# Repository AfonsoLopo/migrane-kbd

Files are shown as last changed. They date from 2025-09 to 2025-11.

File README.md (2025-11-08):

## MIGRANE
<p align="center">
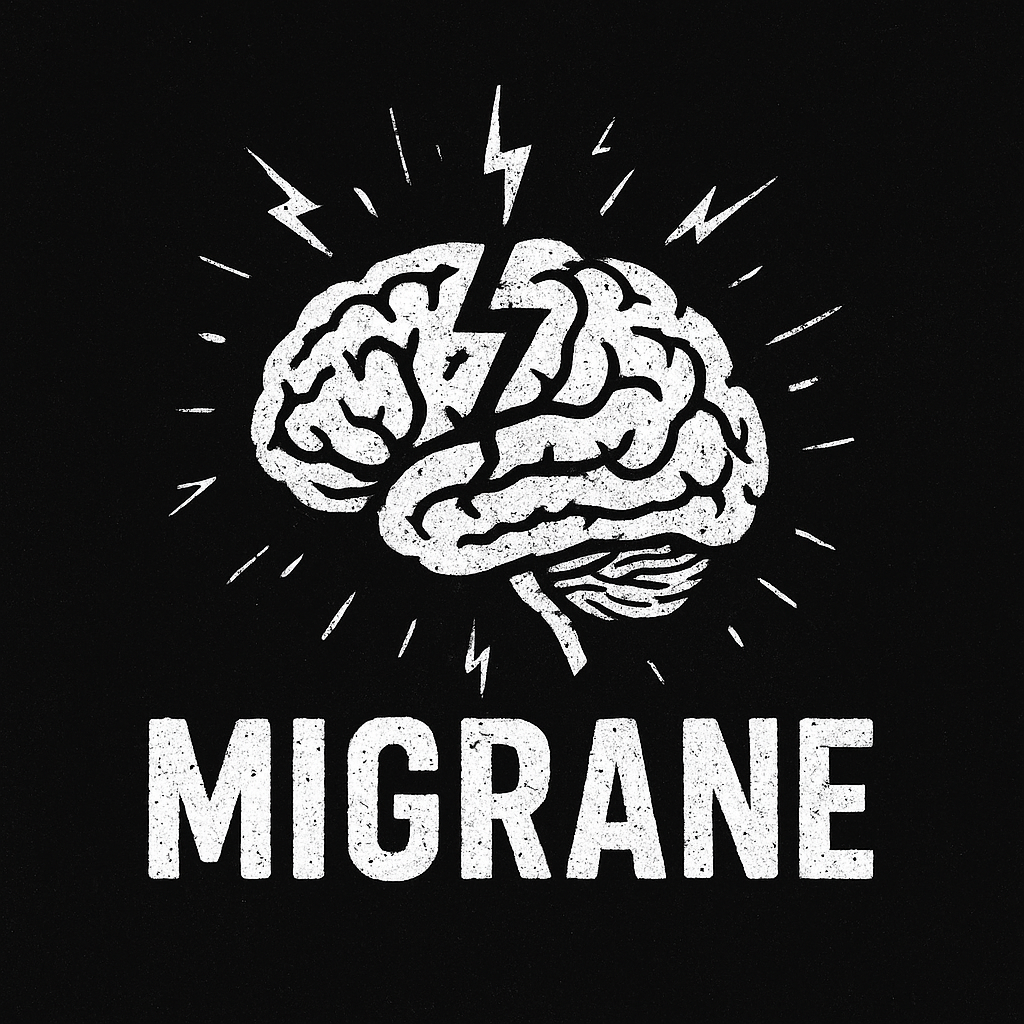
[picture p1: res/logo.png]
Migrane Keyboard logo

</p>

# Table of Contents: 
- [Specs](#Specs)
- [Assembly](#Assemby)
- [Firmware](#Firmware)

## Specs
<b>MCU</b> : STM32F446RCT6
<b>Number of Keys:</b> 64 Kailh choc hotswap sockets
<b>Number of LEDS:</b> 64 SK6812-mini e (1 per key) 
<b>Displays:</b> Adafruit 1.8" TFT Display
<b>Connection between halfs :</b> Serial over USB-C to USB-C cable
<b>Wire Debugger:</b> optional headers

## Assembly

    (TBD)

## Firmware

Board prepared to be used with qmk firmware.

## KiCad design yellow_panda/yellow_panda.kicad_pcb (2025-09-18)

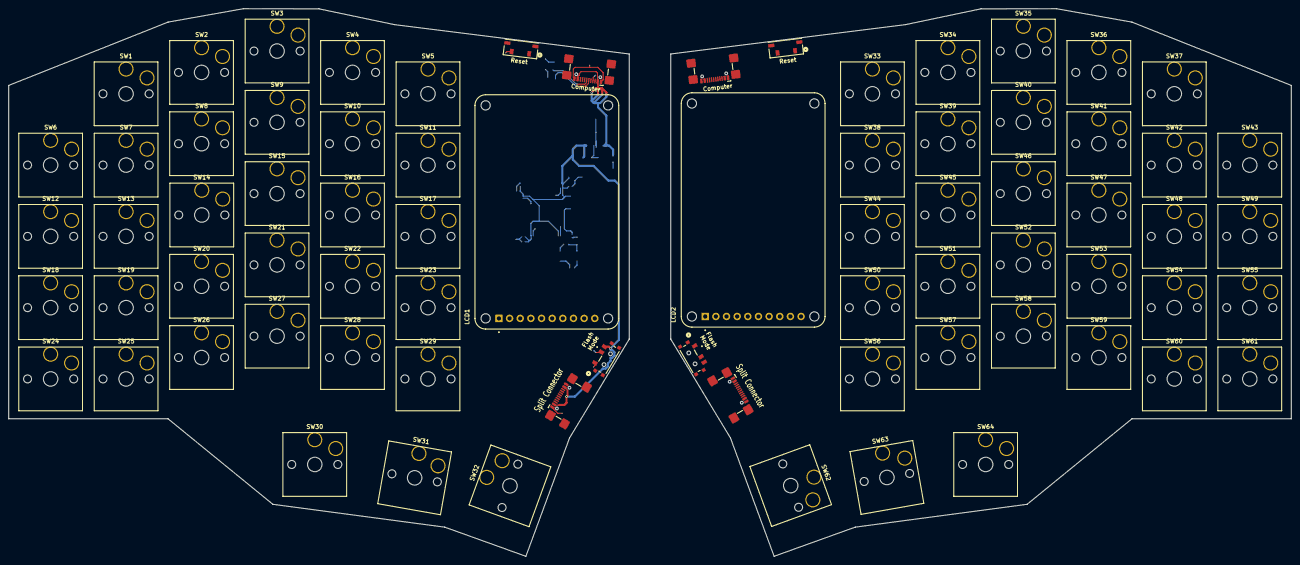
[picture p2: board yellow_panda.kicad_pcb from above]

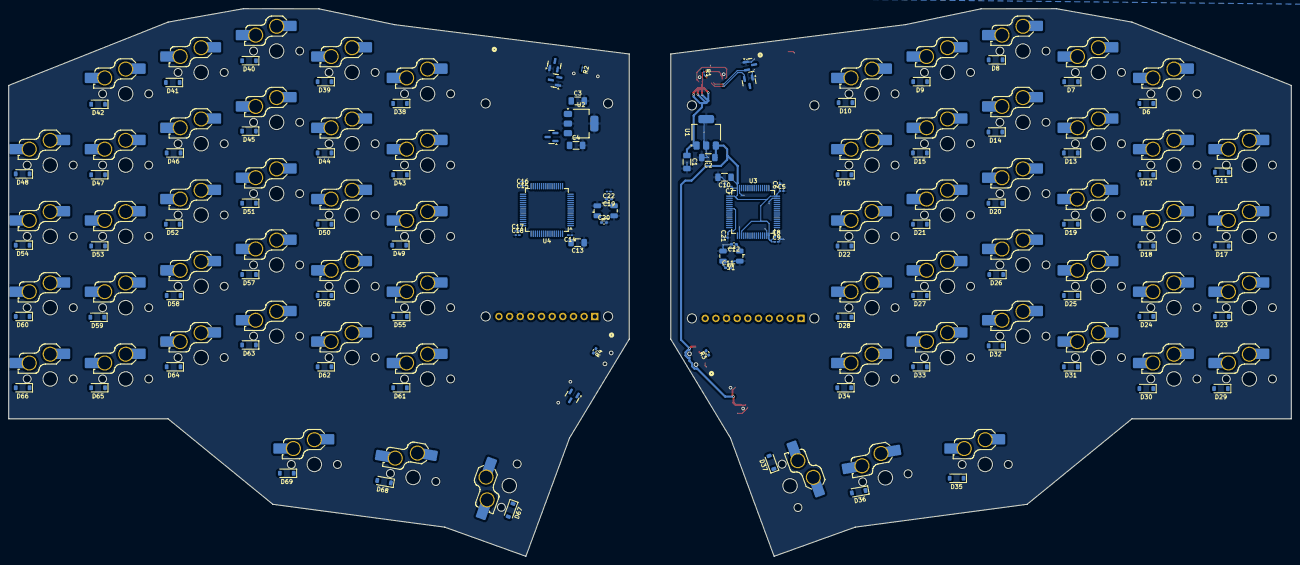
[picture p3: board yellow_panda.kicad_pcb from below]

Board: 2 copper layers, 305.9 x 130.6 mm, 176 parts (102 on the bottom side), 109 nets.

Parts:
C1, C2, C3, C4, C10, C13: 10uF; C_1206_3216Metric_Pad1.33x1.80mm_HandSolder
C5, C6, C7, C8, C9, C14, C15, C16, C17, C18, C21, C22: 100nF; C_0201_0603Metric_Pad0.64x0.40mm_HandSolder
C11, C12, C19, C20: 15pF; C_0402_1005Metric_Pad0.74x0.62mm_HandSolder
D1, D70: D_Schottky; D_SOT-23
D2, D3, D4, D5: 5V; D_SOT-23
D6, D7, D8, D9, D10, D11, D12, D13, D14, D15, D16, D17, D18, D19, D20, D21, D22, D23, D24, D25, D26, D27, D28, D29, D30, D31, D32, D33, D34, D35, D36, D37, D38, D39, D40, D41, D42, D43, D44, D45, D46, D47, D48, D49, D50, D51, D52, D53, D54, D55, D56, D57, D58, D59, D60, D61, D62, D63, D64, D65, D66, D67, D68, D69: D_SOD-123
LCD1, LCD2: I2C LCD; MODULE_358
P1, P2: USB_C_Plug_USB2.0; USB_C_Receptacle_GCT_USB4110
P3: Master Connection Plug; USB_C_Receptacle_GCT_USB4110
P4: Slave Connection Plug; USB_C_Receptacle_GCT_USB4110
R1, R2: 5.1kΩ; R_01005_0402Metric_Pad0.57x0.30mm_HandSolder
R3, R4: 10k; R_0402_1005Metric_Pad0.72x0.64mm_HandSolder
SW1, SW2, SW3, SW4, SW5, SW6, SW7, SW8, SW9, SW10, SW11, SW12, SW13, SW14, SW15, SW16, SW17, SW18, SW19, SW20, SW21, SW22, SW23, SW24, SW25, SW26, SW27, SW28, SW29, SW30, SW31, SW33, SW34, SW35, SW36, SW37, SW38, SW39, SW40, SW41, SW42, SW43, SW44, SW45, SW46, SW47, SW48, SW49, SW50, SW51, SW52, SW53, SW54, SW55, SW56, SW57, SW58, SW59, SW60, SW61, SW63, SW64: SW_Hotswap_Kailh_Choc_V1_Plated_1.00u
SW32, SW62: SW_Hotswap_Kailh_Choc_V1_Plated_1.50u
SW65, SW66: SW_SPDT; SLW-66527511-SMT-TR_CUD
SW67, SW68: SW_Push; SW_TL3330_EWI
U1, U2: LT1963AxST-3.3; SOT-223-3_TabPin2
U3, U4: STM32F446RCTx; LQFP-64_10x10mm_P0.5mm
Y1, Y2: 8MHz; Crystal_SMD_Abracon_ABM3B-4Pin_5.0x3.2mm

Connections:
+3.3V: C2.1, C5.1, C6.1, C7.1, C8.1, C9.1, C10.1, C13.2, C14.2, C15.2, C16.2, C17.2, C18.2, D1.1 (K), D70.1 (K), P3.A4 (VBUS), P3.A9 (VBUS), P3.B4 (VBUS), P3.B9 (VBUS), SW65.3 (C), U1.3 (OUT), U3.1 (VBAT), U3.19 (VDD), U3.32 (VDD), U3.48 (VDD), U3.64 (VDD), U4.1 (VBAT), U4.19 (VDD), U4.32 (VDD), U4.48 (VDD), U4.64 (VDD)
+5V: C1.1, C3.1, P1.A4 (VBUS), P1.A9 (VBUS), P1.B4 (VBUS), P1.B9 (VBUS), P2.A4 (VBUS), P2.A9 (VBUS), P2.B4 (VBUS), P2.B9 (VBUS), U1.1 (IN), U2.1 (IN)
/MasterSwitchMatrix/COL0a: SW6.1, SW12.1, SW18.1, SW24.1
/MasterSwitchMatrix/COL1a: SW1.1, SW7.1, SW13.1, SW19.1, SW25.1
/MasterSwitchMatrix/COL2a: SW2.1, SW8.1, SW14.1, SW20.1, SW26.1
/MasterSwitchMatrix/COL3a: SW3.1, SW9.1, SW15.1, SW21.1, SW27.1, SW30.1
/MasterSwitchMatrix/COL4a: SW4.1, SW10.1, SW16.1, SW22.1, SW28.1, SW31.1
/MasterSwitchMatrix/COL5a: SW5.1, SW11.1, SW17.1, SW23.1, SW29.1, SW32.1
/MasterSwitchMatrix/ROW0a: D6.1 (K), D7.1 (K), D8.1 (K), D9.1 (K), D10.1 (K)
/MasterSwitchMatrix/ROW1a: D11.1 (K), D12.1 (K), D13.1 (K), D14.1 (K), D15.1 (K), D16.1 (K)
/MasterSwitchMatrix/ROW2a: D17.1 (K), D18.1 (K), D19.1 (K), D20.1 (K), D21.1 (K), D22.1 (K)
/MasterSwitchMatrix/ROW3a: D23.1 (K), D24.1 (K), D25.1 (K), D26.1 (K), D27.1 (K), D28.1 (K)
/MasterSwitchMatrix/ROW4a: D29.1 (K), D30.1 (K), D31.1 (K), D32.1 (K), D33.1 (K), D34.1 (K)
/MasterSwitchMatrix/ROW6a: D35.1 (K), D36.1 (K), D37.1 (K)
/STM MCUs/BOOT0a: R3.1, U3.60 (BOOT0)
/STM MCUs/BOOT0b: R4.1, U4.60 (BOOT0)
/STM MCUs/OSC INa: C11.1, Y1.3
/STM MCUs/OSC INb: C19.1, Y2.3
/STM MCUs/OSC OUTa: C12.1, Y1.1
/STM MCUs/OSC OUTb: C20.1, Y2.1
/STM MCUs/RESETa: C21.2, SW67.1, U3.7 (NRST)
/STM MCUs/RESETb: C22.2, SW68.1, U4.7 (NRST)
/STM MCUs/SW_BOOT0a: R3.2, SW65.2 (B)
/STM MCUs/SW_BOOT0b: R4.2, SW66.2 (B)
/SlaveSwitchMatrix/COL0b: SW33.1, SW38.1, SW44.1, SW50.1, SW56.1, SW62.1
/SlaveSwitchMatrix/COL1b: SW34.1, SW39.1, SW45.1, SW51.1, SW57.1, SW63.1
/SlaveSwitchMatrix/COL2b: SW35.1, SW40.1, SW46.1, SW52.1, SW58.1, SW64.1
/SlaveSwitchMatrix/COL3b: SW36.1, SW41.1, SW47.1, SW53.1, SW59.1
/SlaveSwitchMatrix/COL4b: SW37.1, SW42.1, SW48.1, SW54.1, SW60.1
/SlaveSwitchMatrix/COL5b: SW43.1, SW49.1, SW55.1, SW61.1
/SlaveSwitchMatrix/ROW0b: D38.1 (K), D39.1 (K), D40.1 (K), D41.1 (K), D42.1 (K)
/SlaveSwitchMatrix/ROW1b: D43.1 (K), D44.1 (K), D45.1 (K), D46.1 (K), D47.1 (K), D48.1 (K)
/SlaveSwitchMatrix/ROW2b: D49.1 (K), D50.1 (K), D51.1 (K), D52.1 (K), D53.1 (K), D54.1 (K)
/SlaveSwitchMatrix/ROW3b: D55.1 (K), D56.1 (K), D57.1 (K), D58.1 (K), D59.1 (K), D60.1 (K)
/SlaveSwitchMatrix/ROW4b: D61.1 (K), D62.1 (K), D63.1 (K), D64.1 (K), D65.1 (K), D66.1 (K)
/SlaveSwitchMatrix/ROW6b: D67.1 (K), D68.1 (K), D69.1 (K)
/USB_Da+: D2.2 (A), P1.A7 (D-)
/USB_Da-: D4.2 (A), P1.A6 (D+)
/USB_Db+: D3.2 (A), P2.A7 (D-)
/USB_Db-: D5.2 (A), P2.A6 (D+)
GND: C1.2, C2.2, C3.2, C4.2, C5.2, C6.2, C7.2, C8.2, C9.2, C10.2, C11.2, C12.2, C13.1, C14.1, C15.1, C16.1, C17.1, C18.1, C19.2, C20.2, C21.1, C22.1, D2.1 (K), D3.1 (K), D4.1 (K), D5.1 (K), LCD1.8 (VSS), LCD2.8 (VSS), P1.A1 (GND), P1.A12 (GND), P1.B1 (GND), P1.B12 (GND), P1.S1 (SHIELD), P2.A1 (GND), P2.A12 (GND), P2.B1 (GND), P2.B12 (GND), P2.S1 (SHIELD), P3.A1 (GND), P3.A12 (GND), P3.B1 (GND), P3.B12 (GND), P3.S1 (SHIELD), P4.A1 (GND), P4.A12 (GND), P4.B1 (GND), P4.B12 (GND), P4.S1 (SHIELD), R1.1, R2.1, SW65.1 (A), SW66.3 (C), SW67.2, SW68.2, U1.2 (GND), U2.2 (GND), U3.18 (VSS), U3.31 (VSS), U3.47 (VSS), U3.63 (VSS), U4.18 (VSS), U4.31 (VSS), U4.47 (VSS), U4.63 (VSS), Y1.2, Y1.4, Y2.2, Y2.4
unnamed: C4.1, D1.2 (A), U2.3 (OUT)
unnamed: D6.2 (A), SW1.2
unnamed: D7.2 (A), SW2.2
unnamed: D8.2 (A), SW3.2
unnamed: D9.2 (A), SW4.2
unnamed: D10.2 (A), SW5.2
unnamed: D11.2 (A), SW6.2
unnamed: D12.2 (A), SW7.2
unnamed: D13.2 (A), SW8.2
unnamed: D14.2 (A), SW9.2
unnamed: D15.2 (A), SW10.2
unnamed: D16.2 (A), SW11.2
unnamed: D17.2 (A), SW12.2
unnamed: D18.2 (A), SW13.2
unnamed: D19.2 (A), SW14.2
unnamed: D20.2 (A), SW15.2
unnamed: D21.2 (A), SW16.2
unnamed: D22.2 (A), SW17.2
unnamed: D23.2 (A), SW18.2
unnamed: D24.2 (A), SW19.2
unnamed: D25.2 (A), SW20.2
unnamed: D26.2 (A), SW21.2
unnamed: D27.2 (A), SW22.2
unnamed: D28.2 (A), SW23.2
unnamed: D29.2 (A), SW24.2
unnamed: D30.2 (A), SW25.2
unnamed: D31.2 (A), SW26.2
unnamed: D32.2 (A), SW27.2
unnamed: D33.2 (A), SW28.2
unnamed: D34.2 (A), SW29.2
unnamed: D35.2 (A), SW30.2
unnamed: D36.2 (A), SW31.2
unnamed: D37.2 (A), SW32.2
unnamed: D38.2 (A), SW33.2
unnamed: D39.2 (A), SW34.2
unnamed: D40.2 (A), SW35.2
unnamed: D41.2 (A), SW36.2
unnamed: D42.2 (A), SW37.2
unnamed: D43.2 (A), SW38.2
unnamed: D44.2 (A), SW39.2
unnamed: D45.2 (A), SW40.2
unnamed: D46.2 (A), SW41.2
unnamed: D47.2 (A), SW42.2
unnamed: D48.2 (A), SW43.2
unnamed: D49.2 (A), SW44.2
unnamed: D50.2 (A), SW45.2
unnamed: D51.2 (A), SW46.2
unnamed: D52.2 (A), SW47.2
unnamed: D53.2 (A), SW48.2
unnamed: D54.2 (A), SW49.2
unnamed: D55.2 (A), SW50.2
unnamed: D56.2 (A), SW51.2
unnamed: D57.2 (A), SW52.2
unnamed: D58.2 (A), SW53.2
unnamed: D59.2 (A), SW54.2
unnamed: D60.2 (A), SW55.2
unnamed: D61.2 (A), SW56.2
unnamed: D62.2 (A), SW57.2
unnamed: D63.2 (A), SW58.2
unnamed: D64.2 (A), SW59.2
unnamed: D65.2 (A), SW60.2
unnamed: D66.2 (A), SW61.2
unnamed: D67.2 (A), SW62.2
unnamed: D68.2 (A), SW63.2
unnamed: D69.2 (A), SW64.2
unnamed: D70.2 (A), P4.A4 (VBUS), P4.A9 (VBUS), P4.B4 (VBUS), P4.B9 (VBUS)
unnamed: P1.A5 (CC), R1.2
unnamed: P2.A5 (CC), R2.2

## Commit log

2025-09-18 Everything is in place now
    Swap STM MCU, Correct Switches,
    add diodes, caps and resistors
    [clocks.kicad_sch, i2c_devices.kicad_sc.kicad_sch, lcds.kicad_sch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]
2025-09-18 Added some routing to power lines
    [mcu.kicad_sch, yellow_panda.kicad_pcb, yellow_panda.kicad_sch]
2025-09-19 rev0.1a - master half done
    [Led.kicad_sch, MasterLed.kicad_sch, bom.csv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]
2025-09-20 Finished the design
    [MasterLed.kicad_sch, SlaveLed.kicad_sch, bom.csv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]
2025-10-06 Update after fabrication
    [bom.csv, designators.csv, mcu.kicad_sch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]
2025-10-11 rename to pandakbd
    [Led.kicad_sch, MasterLed.kicad_sch, SlaveLed.kicad_sch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]
2025-11-03 reorganization of the repo and yet another rename
    [MasterLed.kicad_sch, SlaveLed.kicad_sch, left.kicad_sch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]
2025-11-04 start with leds
    [MasterLed.kicad_sch, migrane.kicad_pcb]
2025-11-05 Finish Layout for Master Half.
    - Unimplemented handedness yet.
    - Rest of the board should be working already
    [left.kicad_sch, right.kicad_sch]
2025-11-06 ongoing work
    [left.kicad_sch, right.kicad_sch]
2025-11-08 Change LDI3.3 LCSC part number to Diotec part
    [left.kicad_sch, right.kicad_sch]
